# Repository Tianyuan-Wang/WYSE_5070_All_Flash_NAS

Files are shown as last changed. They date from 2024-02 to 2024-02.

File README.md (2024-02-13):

# WYSE_5070_All_Flash_NAS

最近买了个二手的WYSE 5070瘦客户机打算用作低功耗NAS。由于不是Extended版本，需要对硬件进行改动来安装额外的硬盘。

之前看了[KCORES的教程](https://youtu.be/9opQ4gsh4Hg?si=m19QCSclOVte6yVY)，给主板加了PCIE插槽但是配套的Riser卡放不进机箱，而且需要搭配12V电源。

于是一切为了美观，设计了一个自带19V转12V的矮版转接卡，配合PCIE桥接卡可以拓展4个M.2 NVME SSD。配合机箱内部预留的螺丝孔位，正好可以3D打印个支架用来固定扩展卡。

## 硬件改动

1. 需要切掉原本用来固定背板扩展卡的两个金属片。以及将3D打印的NVME扩展卡支架用M3x10螺丝安装到机箱内。

2. 需要将NVME扩展卡末端切掉5mm，否则机箱盖子盖不上。（这里用的是SSU SU-EM5204(A3)版的扩展卡，链接就不放了，某宝有卖。）没用更高速的版本是因为散热器高度的问题，这里我把原本10mm的散热片剪成了6mm高度，正好能放下。如果能找到合适的散热片，推荐买高速版本，因为5204-A3上行是3.0x2而主板是2.0x4，浪费了很多。机箱外壳是金属的，可以加散热贴通过机箱散热。

## 安装注意

1. 安装扩展卡的时候，要先把NVME扩展卡插入Riser卡里再一起插入主板PCIE插槽，否则没法装扩展卡。

2. 如果是和我一样用的无EMMC版本的，需要先安装扩展卡支架再安装主板上的SATA SSD。

## 示意图

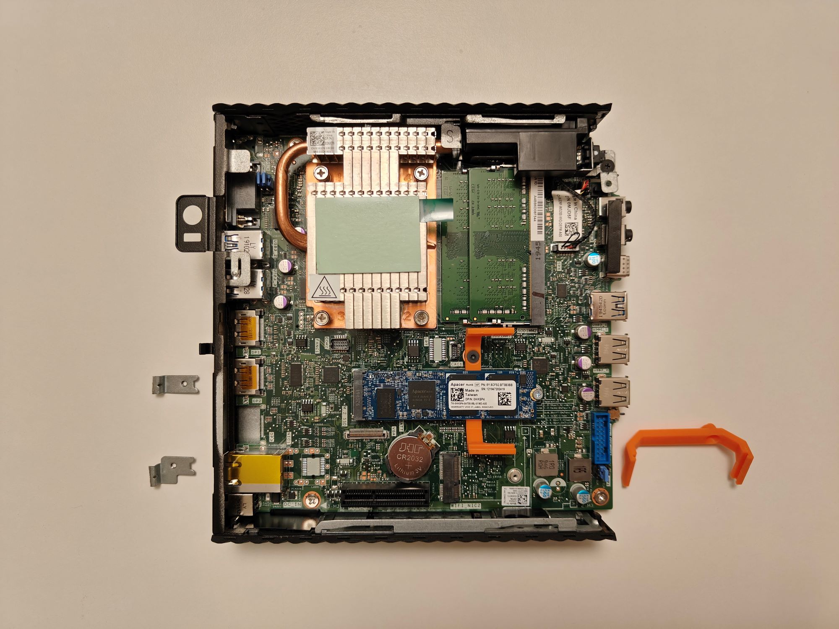
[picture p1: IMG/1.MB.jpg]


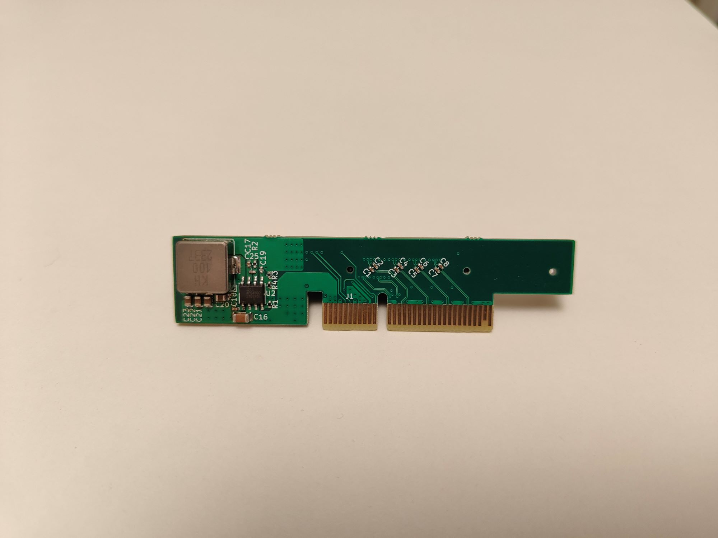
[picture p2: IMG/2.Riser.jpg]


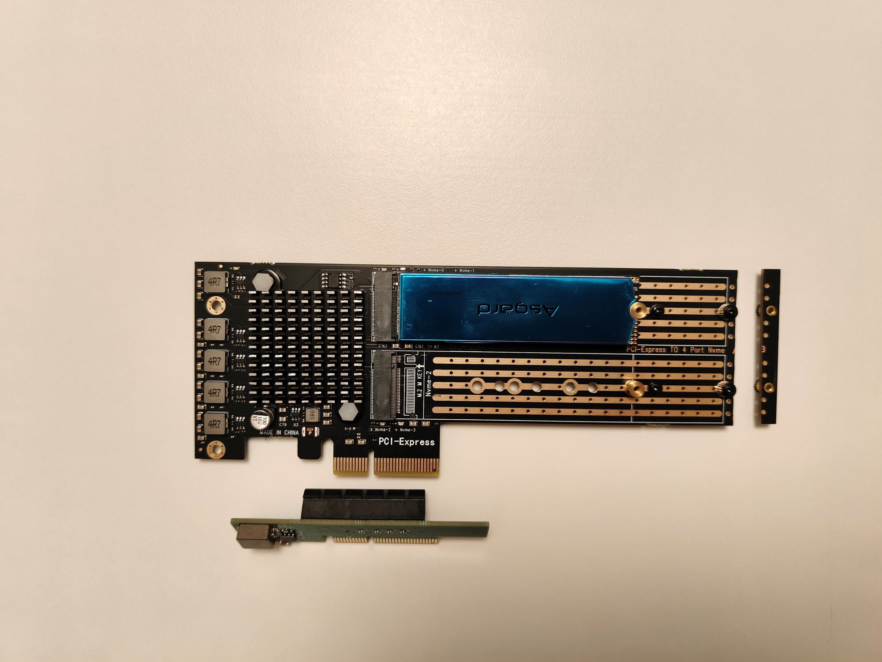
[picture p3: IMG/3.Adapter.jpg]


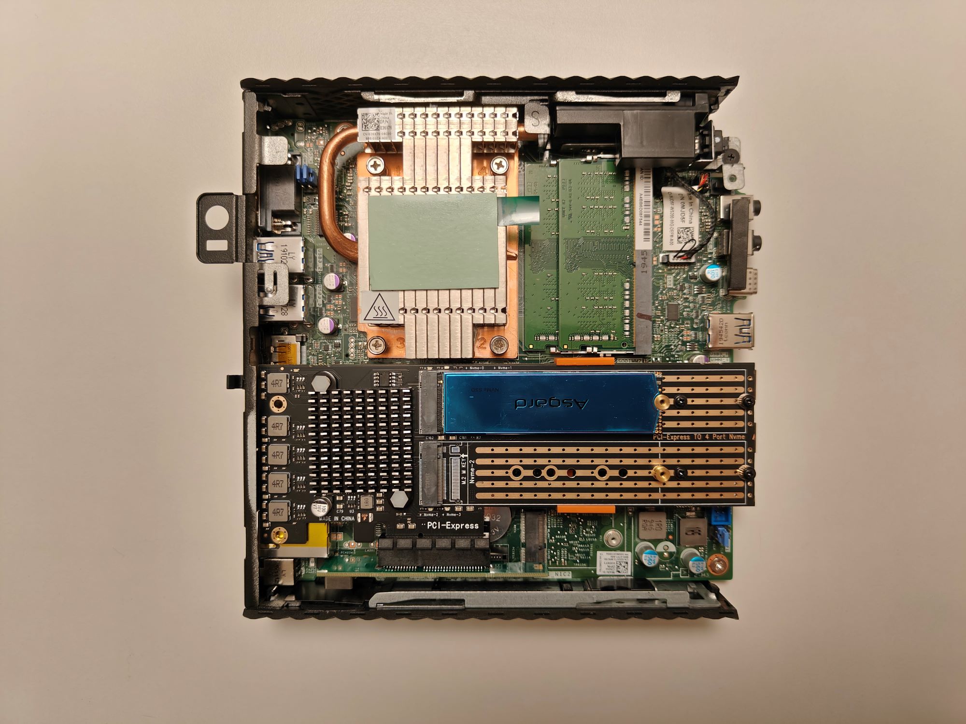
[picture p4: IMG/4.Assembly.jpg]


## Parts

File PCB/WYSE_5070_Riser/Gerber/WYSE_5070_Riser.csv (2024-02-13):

Comment | Designator | Footprint | LCSC
100nF | C1,C2,C3,C4,C5,C6,C7,C8,C18 | Capacitor_SMD:C_0402_1005Metric
10uF | C16 | Capacitor_SMD:C_1206_3216Metric
2.7nF | C17 | Capacitor_SMD:C_0402_1005Metric
100pF | C19 | Capacitor_SMD:C_0402_1005Metric
22uF | C20,C21,C22,C23 | Capacitor_SMD:C_0805_2012Metric
15pF | C25 | Capacitor_SMD:C_0402_1005Metric
Riser_Edge_to_MB | J1 | WYSE_5070_Riser:BUS_PCIexpress_x4_Short
Riser_Receptable_to_Card | J2 | WYSE_5070_Riser:PCIEx4_SMD_Narrow
10uH | L2 | Inductor_SMD:L_Bourns_SRP1038C_10.0x10.0mm
100k | R1 | Resistor_SMD:R_0402_1005Metric
37.4k | R2 | Resistor_SMD:R_0402_1005Metric
309k | R3 | Resistor_SMD:R_0402_1005Metric
22.1k | R4 | Resistor_SMD:R_0402_1005Metric
AP64500SP-13 | U2 | WYSE_5070_Riser:SO-8EP_DIO

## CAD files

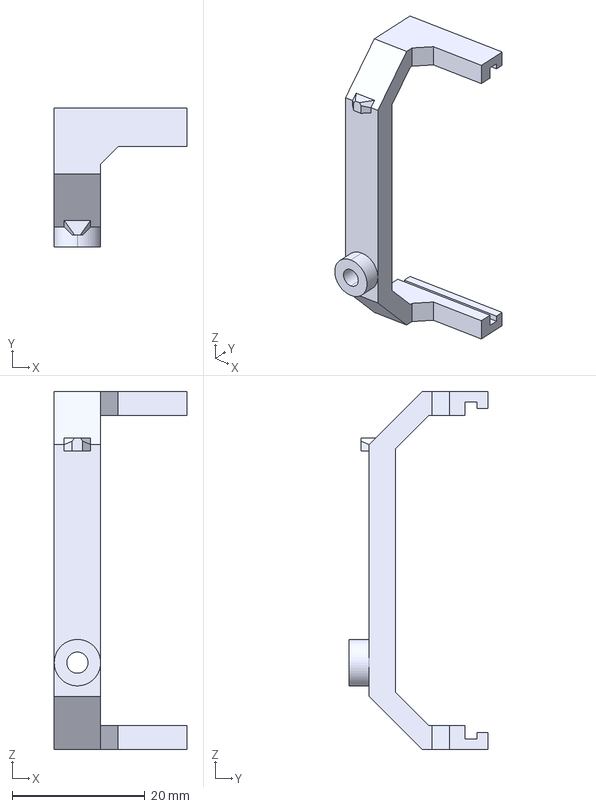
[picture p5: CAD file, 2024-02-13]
CAD/M.2 NVME Adapter Holder.step
20.0 x 20.9 x 54.0 mm

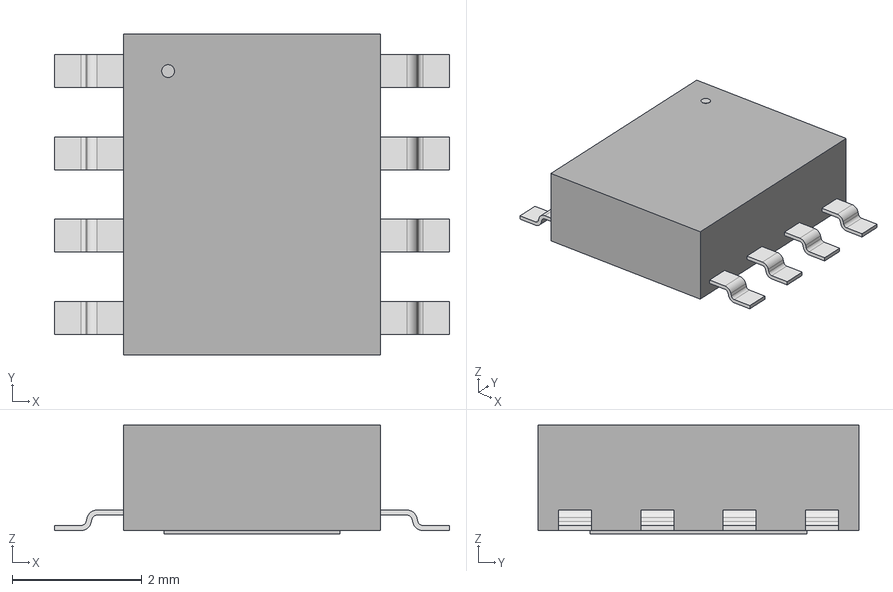
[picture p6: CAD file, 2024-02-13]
PCB/WYSE_5070_Riser/External Resources/AP64500SP_13/SO-8EP_DIO.step
6.10 x 4.95 x 1.68 mm

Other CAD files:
PCB/WYSE_5070_Riser/External Resources/AP64500SP_13/SO-8EP_DIO.iges

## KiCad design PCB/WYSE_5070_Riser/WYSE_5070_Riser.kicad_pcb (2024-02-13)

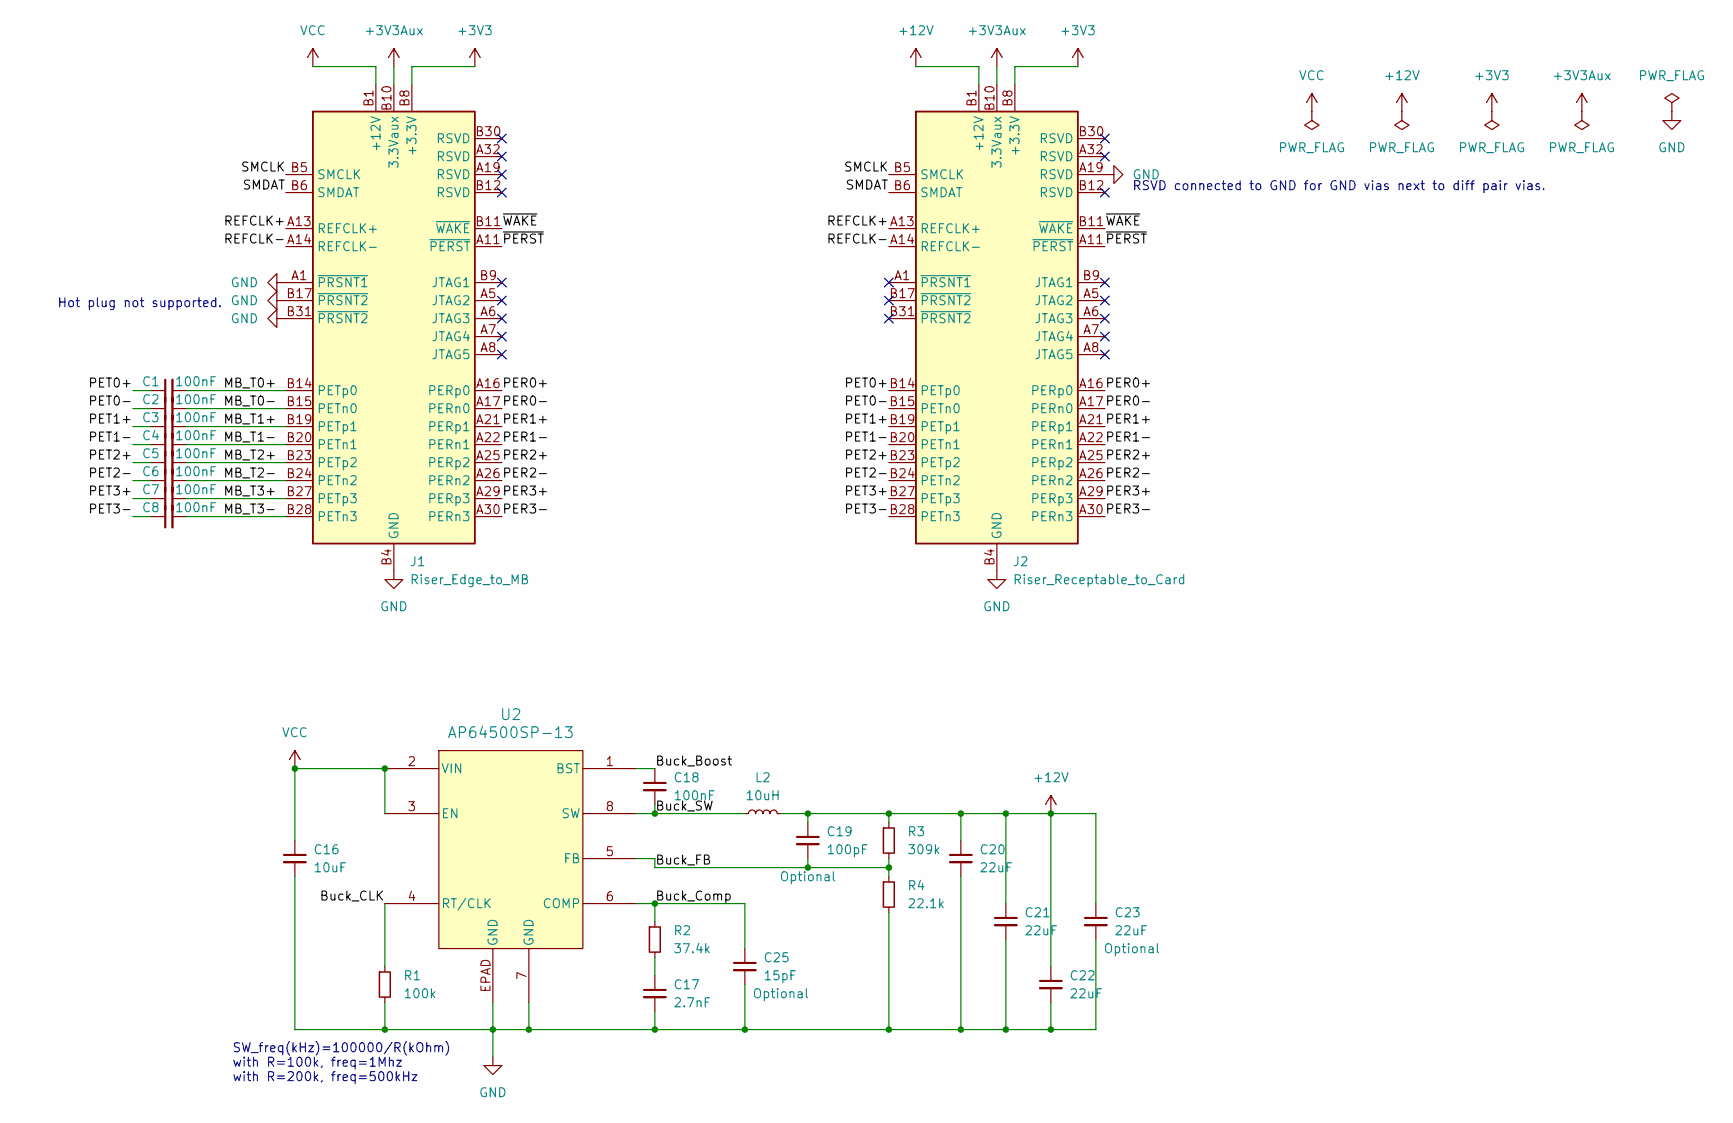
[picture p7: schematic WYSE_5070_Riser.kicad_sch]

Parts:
C1, C2, C3, C4, C5, C6, C7, C8, C18: 100nF; C_0402_1005Metric
C16: 10uF; C_1206_3216Metric
C17: 2.7nF; C_0402_1005Metric
C19: 100pF; C_0402_1005Metric
C20, C21, C22, C23: 22uF; C_0805_2012Metric
C25: 15pF; C_0402_1005Metric
J1: Riser_Edge_to_MB; BUS_PCIexpress_x4_Short
J2: Riser_Receptable_to_Card; PCIEx4_SMD_Narrow
L2: 10uH; L_Bourns_SRP1038C_10.0x10.0mm
R1: 100k; R_0402_1005Metric
R2: 37.4k; R_0402_1005Metric
R3: 309k; R_0402_1005Metric
R4: 22.1k; R_0402_1005Metric
U2: AP64500SP-13; SO-8EP_DIO

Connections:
+3V3: J1.A9 (+3.3V), J1.A10 (+3.3V), J1.B8 (+3.3V), J2.A9 (+3.3V), J2.A10 (+3.3V), J2.B8 (+3.3V)
+3V3Aux: J1.B10 (3.3Vaux), J2.B10 (3.3Vaux)
+12V: C19.1, C20.1, C21.1, C22.1, C23.1, J2.A2 (+12V), J2.A3 (+12V), J2.B1 (+12V), J2.B2 (+12V), J2.B3 (+12V), L2.2, R3.1
/Buck_Boost: C18.1, U2.1 (BST)
/Buck_CLK: R1.1, U2.4 (RT/CLK)
/Buck_Comp: C25.1, R2.1, U2.6 (COMP)
/Buck_FB: C19.2, R3.2, R4.1, U2.5 (FB)
/Buck_SW: C18.2, L2.1, U2.8 (SW)
/MB_T0+: C1.2, J1.B14 (PETp0)
/MB_T0-: C2.2, J1.B15 (PETn0)
/MB_T1+: C3.2, J1.B19 (PETp1)
/MB_T1-: C4.2, J1.B20 (PETn1)
/MB_T2+: C5.2, J1.B23 (PETp2)
/MB_T2-: C6.2, J1.B24 (PETn2)
/MB_T3+: C7.2, J1.B27 (PETp3)
/MB_T3-: C8.2, J1.B28 (PETn3)
/PER0+: J1.A16 (PERp0), J2.A16 (PERp0)
/PER0-: J1.A17 (PERn0), J2.A17 (PERn0)
/PER1+: J1.A21 (PERp1), J2.A21 (PERp1)
/PER1-: J1.A22 (PERn1), J2.A22 (PERn1)
/PER2+: J1.A25 (PERp2), J2.A25 (PERp2)
/PER2-: J1.A26 (PERn2), J2.A26 (PERn2)
/PER3+: J1.A29 (PERp3), J2.A29 (PERp3)
/PER3-: J1.A30 (PERn3), J2.A30 (PERn3)
/PET0+: C1.1, J2.B14 (PETp0)
/PET0-: C2.1, J2.B15 (PETn0)
/PET1+: C3.1, J2.B19 (PETp1)
/PET1-: C4.1, J2.B20 (PETn1)
/PET2+: C5.1, J2.B23 (PETp2)
/PET2-: C6.1, J2.B24 (PETn2)
/PET3+: C7.1, J2.B27 (PETp3)
/PET3-: C8.1, J2.B28 (PETn3)
/REFCLK+: J1.A13 (REFCLK+), J2.A13 (REFCLK+)
/REFCLK-: J1.A14 (REFCLK-), J2.A14 (REFCLK-)
/SMCLK: J1.B5 (SMCLK), J2.B5 (SMCLK)
/SMDAT: J1.B6 (SMDAT), J2.B6 (SMDAT)
/~PERST: J1.A11 (~PERST), J2.A11 (~PERST)
/~WAKE: J1.B11 (~WAKE), J2.B11 (~WAKE)
GND: C16.2, C17.2, C20.2, C21.2, C22.2, C23.2, C25.2, J1.A1 (~PRSNT1), J1.A4 (GND), J1.A12 (GND), J1.A15 (GND), J1.A18 (GND), J1.A20 (GND), J1.A23 (GND), J1.A24 (GND), J1.A27 (GND), J1.A28 (GND), J1.A31 (GND), J1.B4 (GND), J1.B7 (GND), J1.B13 (GND), J1.B16 (GND), J1.B17 (~PRSNT2), J1.B18 (GND), J1.B21 (GND), J1.B22 (GND), J1.B25 (GND), J1.B26 (GND), J1.B29 (GND), J1.B31 (~PRSNT2), J1.B32 (GND), J2.A4 (GND), J2.A12 (GND), J2.A15 (GND), J2.A18 (GND), J2.A19 (RSVD), J2.A20 (GND), J2.A23 (GND), J2.A24 (GND), J2.A27 (GND), J2.A28 (GND), J2.A31 (GND), J2.B4 (GND), J2.B7 (GND), J2.B13 (GND), J2.B16 (GND), J2.B18 (GND), J2.B21 (GND), J2.B22 (GND), J2.B25 (GND), J2.B26 (GND), J2.B29 (GND), J2.B32 (GND), R1.2, R4.2, U2.7 (GND), U2.EPAD (GND)
unnamed: C17.1, R2.2
VCC: C16.1, J1.A2 (+12V), J1.A3 (+12V), J1.B1 (+12V), J1.B2 (+12V), J1.B3 (+12V), U2.2 (VIN), U2.3 (EN)

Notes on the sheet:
Hot plug not supported.
SW_freq(kHz)=100000/R(kOhm) with R=100k, freq=1Mhz with R=200k, freq=500kHz
RSVD connected to GND for GND vias next to diff pair vias.

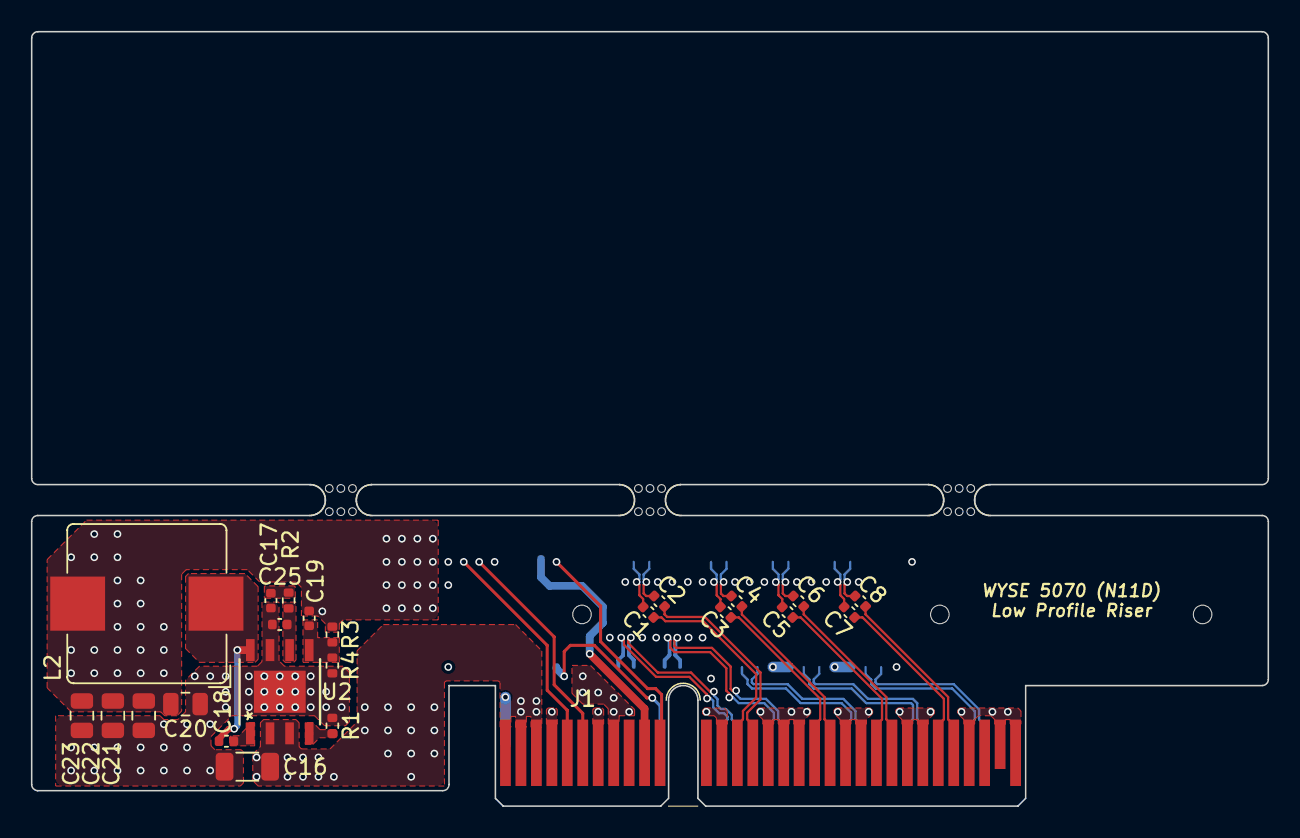
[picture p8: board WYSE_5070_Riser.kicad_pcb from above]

Board: 4 copper layers, 80.0 x 50.1 mm, 28 parts (1 on the bottom side), 41 nets.

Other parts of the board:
mouse-bite-2mm-slot, mouse-bite-2mm-slot#2, mouse-bite-2mm-slot#3: VAL**; mouse-bite-2mm-slot
